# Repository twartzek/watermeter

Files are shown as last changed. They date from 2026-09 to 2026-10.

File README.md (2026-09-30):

# WatermeterAI NextGen 💧

Turns a photo of an ordinary analog water meter into a continuous digital reading — no smart meter, no retrofit, just a Raspberry Pi, a camera, and a YOLO model reading the dials like a person would.







<p align="center">
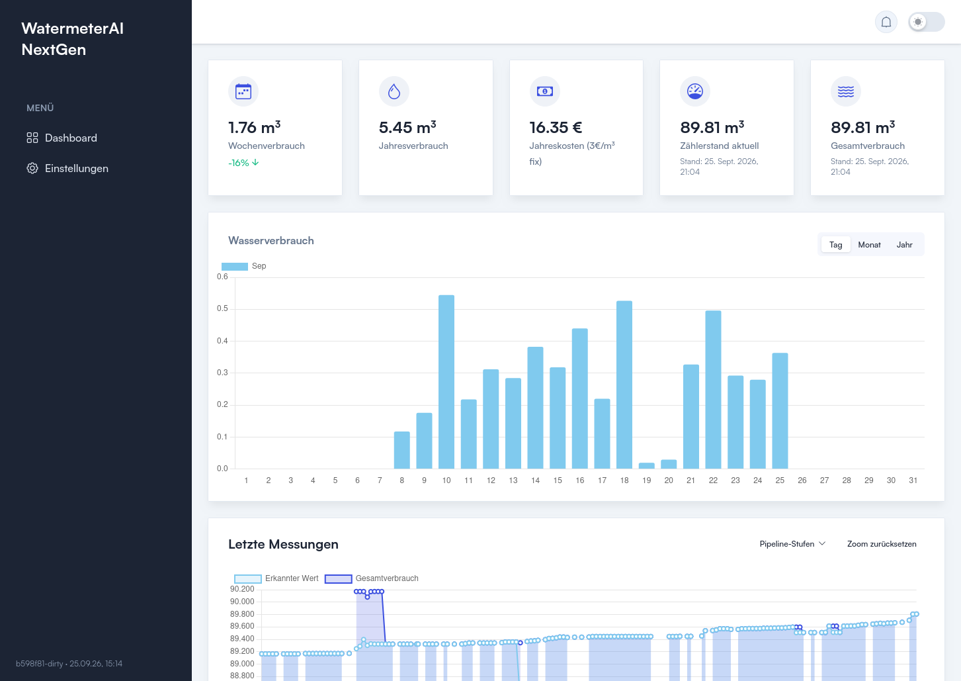
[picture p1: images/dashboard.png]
WatermeterAI NextGen dashboard
  
</p>

Every 15 minutes, a camera photographs the meter's dial face and a pair of YOLO models reads the digit wheels and sweep needles into one cumulative value, which is filtered for outliers, stored, and pushed to a dashboard and MQTT. A nightly job watches the trend for the signature of a leak and emails a warning before it becomes a water bill.

## Contents

- [WatermeterAI NextGen 💧](#watermeterai-nextgen-)
  - [Contents](#contents)
  - [Installation](#installation)
  - [Local development](#local-development)
    - [Verifying a deploy](#verifying-a-deploy)
  - [Configuration reference](#configuration-reference)
  - [How it works](#how-it-works)
  - [Model training](#model-training)
  - [Hardware](#hardware)
    - [What it costs](#what-it-costs)
  - [Leak detection](#leak-detection)
  - [Repository layout](#repository-layout)
  - [Known limitations](#known-limitations)
  - [Credits](#credits)
  - [License](#license)

## Installation

The intended target is a fresh Raspberry Pi OS install (Bullseye or newer, 64-bit recommended for `torch`/`ultralytics`).

```bash
git clone https://github.com/twartzek/watermeter
cd watermeter
sudo bash setupscript.sh
```

`setupscript.sh` is idempotent-ish but not fully — read it before running it twice. It will:

1. Increase swap to 2 GB (YOLO inference is memory-hungry on a Pi Zero 2)
2. Install system packages (`python3-picamera2`, `zbar-tools`, `npm`, `watchdog`)
3. Create a Python venv and install the pinned backend dependencies
4. Write `/home/admin/watermeter/.env` with the paths the backend expects
5. Register two `systemd` services and three cron jobs (measurement every 15 min, leak check nightly, photo cleanup nightly)
   - Readings are kept at full 15-minute resolution forever. At ~100 bytes per row that is only ~4 MB per year, and the leak detector's baseline window (`BASELINE_LOOKBACK_DAYS`, currently 30 days) can be extended if needed.
   - The photos are what fills the SD card, so the nightly cleanup keeps every photo for the last 30 days only. On older days it keeps just the photos of the first and last reading, and it also removes older orphaned photos from failed recognitions.
6. Configure a hardware watchdog that reboots the Pi if the reading log goes stale

Build the frontend once, so the systemd service has something to serve:

```bash
cd frontend
npm install
npm run build   # outputs to frontend/dist, served by `serve` on :80
```

On first boot with no WiFi configured, `backend/wifi.py` waits for a WiFi-credentials QR code (printed on a router, or from any "share WiFi" phone feature) to be shown to the camera — no keyboard or monitor needed.

## Local development

No Pi or camera needed to work on the dashboard/API — `requirements.txt` covers everything else:

```bash
cd backend
python3 -m venv .venv && source .venv/bin/activate
pip install -r requirements.txt

cp .env.example watermeter/.env   # see Configuration reference below
python seed_dev_data.py           # optional: populate SQLite with sample readings
python restapi.py                 # → http://localhost:8000/api/v1
```

```bash
cd frontend
npm install
npm run dev                       # → http://localhost:5173
```

Run the test suite with:

```bash
cd backend
pytest
```

`requirements-pi.txt` (`ultralytics`, `torch`, `opencv-python`, `pyzbar`, `Pillow`) is only needed for the actual image-reading pipeline, on hardware that can run YOLO inference.

### Verifying a deploy

Every frontend build stamps itself with its short git commit hash (`git rev-parse --short HEAD` in [`frontend/vite.config.js`](frontend/vite.config.js), plus `-dirty` for uncommitted changes), shown at the bottom of the dashboard sidebar — compare it against your local `git rev-parse --short HEAD` after `deploy.sh` to confirm the Pi picked up the latest build.

## Configuration reference

Install-specific config lives in two places, both deliberately excluded from version control:

| File | Holds | Set by |
|---|---|---|
| `watermeter/.env` | Filesystem paths — DB file, image folder, log folder, model weight paths | `setupscript.sh` on install |
| `data/settings.json` | MQTT broker credentials, SMTP credentials | Dashboard's Settings page, or manually on first run |

> **Network exposure:** The REST API has permissive CORS and no authentication — built for a trusted home LAN. Don't port-forward `:8000`/`:80` without a reverse proxy and auth in front.

## How it works

```mermaid
flowchart TB
    cam["📷 Pi Camera<br/><small>every 15 min</small>"]
    read["readTotalConsumption.py<br/><small>2× YOLO11<br/>digits + needles</small>"]
    presence["missing-box check<br/><small>discard incomplete reads</small>"]
    filt["outlierDetection.py<br/><small>digit · flow · delta<br/>filters</small>"]
    db[("SQLite<br/><small>readings + images</small>")]
    mqtt["MQTT broker"]
    api["restapi.py<br/><small>FastAPI :8000</small>"]
    dash["React dashboard<br/><small>:80</small>"]
    leak["leakageDetector.py<br/><small>Z-score + Isolation<br/>Forest · daily</small>"]
    warn["✉️ Email + MQTT<br/><small>notifications</small>"]
    wdog["watchdog<br/><small>reboots on hang</small>"]

    cam -->|photo| read
    read -->|raw m³| presence
    presence -->|passed| filt
    filt -->|store| db
    db -->|publish| mqtt
    db -->|read| api
    api -->|JSON| dash
    db -.->|30-day history| leak
    leak -.->|3× flagged| warn
    read -.->|watches for a hang| wdog

    style read fill:#b5672f,color:#fff,stroke:#8a4d22
    style db fill:#b5672f,color:#fff,stroke:#8a4d22
    style api fill:#b5672f,color:#fff,stroke:#8a4d22
    style leak fill:#b5672f,color:#fff,stroke:#8a4d22
```

*Solid arrows run every 15 minutes; dashed arrows (leak detector) run nightly and only speak up after three consecutive flagged days. A watchdog reboots the Pi if a run ever hangs.*

**Reading pipeline.** Two YOLO11 models read the digit wheels and sweep needles into a cumulative m³ value; a red-pixel check locates the decimal point, since the fractional wheels are printed red.

<p align="center">
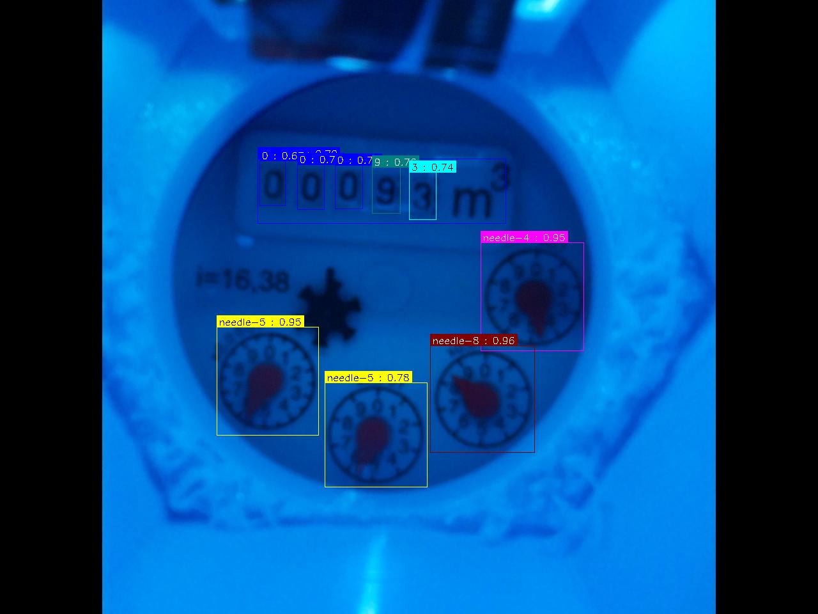
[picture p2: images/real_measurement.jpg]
YOLO detections on a real meter photo: five digit boxes and four needle boxes with confidence scores
  
</p>

*A real frame from the housing camera: the digit model finds each wheel (`0 0 0 9 3`), the needle model reads the four red dials — together 93.4855 m³.*

**Outlier filtering.** A missing-box check discards incomplete frames outright. Accepted values then pass missing-digit, max-flow (rate + absolute cap), and negative-delta filters — a single bad reading falls back to the local median, but a sustained run of consistent higher readings is accepted as real (e.g. a pipe burst) and triggers a notification instead of being clamped forever.

**Storage and delivery.** Readings, images, and every intermediate pipeline value land in SQLite, publish to MQTT, and are served by FastAPI to the React dashboard. Developer mode exposes each pipeline stage as its own chart line.

## Model training

The two YOLO11 models in `backend/models/` were trained on **3,516 images** from several sources — web photos, synthetically generated dials, and composited images — to cover a wide range of meter appearances, lighting, and angles, so the model doesn't overfit to one setup.

| Model | Task | Precision | Recall | mAP50 | mAP50-95 | Epochs |
|---|---|---|---|---|---|---|
| `totalandneedles/best.pt` | Needle position + counter-area detection | 0.894 | 0.882 | 0.906 | 0.852 | 100 |
| `digits/best.pt` | Digit-wheel detection (0–9 + red/transition class) | 0.964 | 0.908 | 0.948 | 0.826 | 100 |

The higher digit-detection precision (0.96 vs. 0.89) reflects that digit wheels are a more visually consistent target than needle position, which varies more geometrically across meter models. The two models' errors are largely independent, which is part of why the outlier filters downstream catch what either model gets wrong on its own.

If retraining for a different meter design, keep the same split (needles/counter-area vs. digit wheels). Training scripts and the raw dataset aren't included here, but the label format follows standard Ultralytics YOLO conventions — any compatible pipeline (e.g. [Roboflow](https://roboflow.com) or local [Ultralytics](https://docs.ultralytics.com/)) will work.

## Hardware

`Raspberry Pi Zero 2 W (or better)` · `Pi Camera Module` · `Custom LED light (KiCad)` · `3D-printed mount (FreeCAD)`

<p align="center">
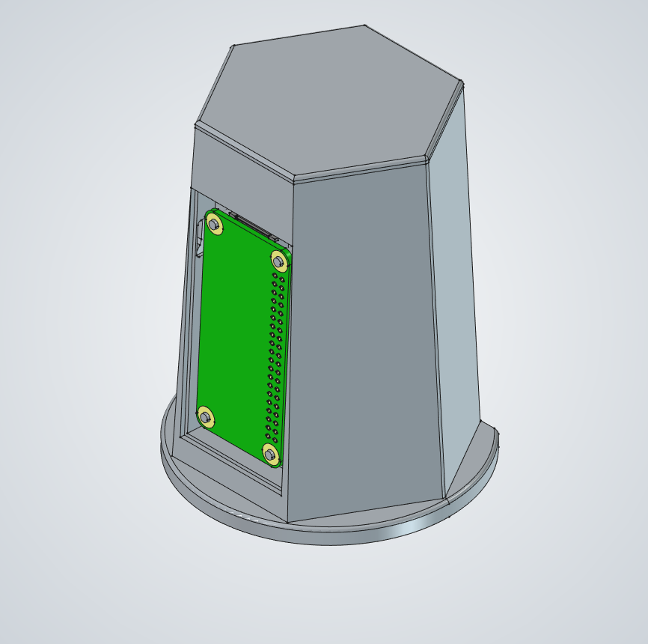
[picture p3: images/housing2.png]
CAD model of the camera and LED housing
  
  &nbsp;&nbsp;
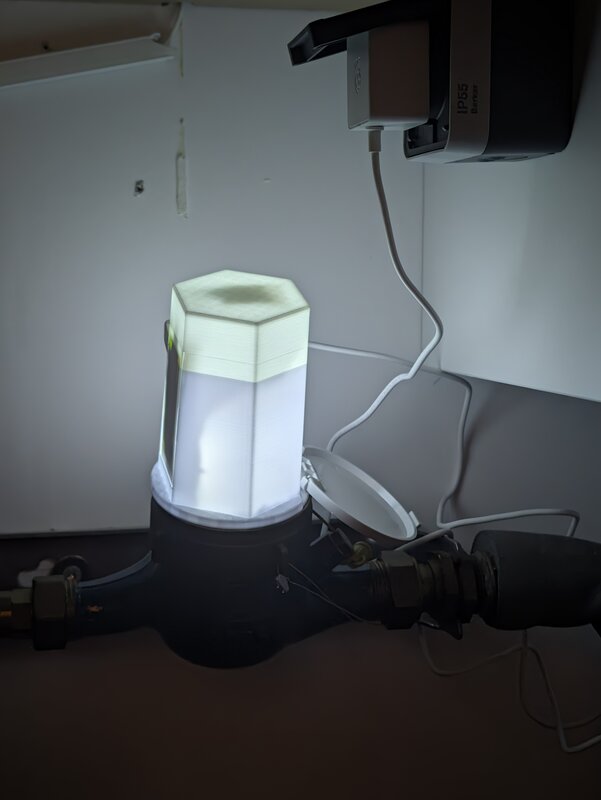
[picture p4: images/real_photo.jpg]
Printed housing installed on a real water meter, LED lit
  
</p>
<p align="center"><sub>Left: FreeCAD model · Right: installed on the meter</sub></p>

The camera and a custom LED light source (schematic/PCB in [`hardware/led/`](hardware/led/)) sit inside a 3D-printed bracket ([`mechanics/`](mechanics/)) that clips over the meter's glass face — no plumbing work, no meter replacement. Camera and LED are offset from each other at an angle chosen so the glass's specular reflection is thrown away from the camera instead of back into it, which is the single biggest source of misreads.

### What it costs

The compute and imaging side is deliberately cheap — accuracy comes from the YOLO models and lighting, not the hardware:

| Part | Price |
| --- | --- |
| Raspberry Pi Zero 2 W | ~€20 / $15 |
| Camera module (e.g. RPIZ-CAM-GS) | ~€15 |
| **Total (board + camera)** | **~€35 / ~$40** |

Add a power supply, SD card, the LED board, and a printed bracket (see [`hardware/`](hardware/) and [`mechanics/`](mechanics/)) and you're realistically still under €50 all in. Prices fluctuate by retailer; check current listings.

> **Reproducing the hardware:** PCB and enclosure files are provided as-is. You'll need KiCad for `hardware/led/led.kicad_pcb` and FreeCAD for the `mechanics/*.FCStd` models — expect to adapt the bracket geometry, since glass diameter/depth vary by meter manufacturer.

## Leak detection

`leakageDetector.py` runs nightly and combines three independent signals, since a slow leak, a stuck-open valve, and a burst pipe each look different in the reading history:

| Check | Catches | How |
|---|---|---|
| Rest-period check | Flow that never fully stops in 24h | Looks for any window where consecutive readings stay within an adaptive noise threshold |
| Z-score model | A quiet-hour slot (e.g. 3am) running unusually high | Compares each time-of-day slot's rolling 30-min sum against its own 30-day distribution |
| Isolation Forest | Unusual combinations — steady flow at an odd hour, an odd-sized single spike | Unsupervised model trained on flow, streak length, and time-of-day features |

A single flagged night doesn't trigger a warning — three consecutive nights do, trading a day or two of latency for not emailing you every time the dishwasher runs at an odd hour.

## Repository layout

| Path | What lives there |
|---|---|
| `backend/` | FastAPI server, YOLO reading pipeline, leak detector, SQLite models |
| `backend/models/` | Trained YOLO11 weights (digits, needles+counter-area) |
| `backend/tests/` | Pytest suite — pure-function tests + a DB-backed integration test |
| `frontend/` | React + Vite dashboard (readings, charts, settings, notifications) |
| `hardware/led/` | KiCad schematic + PCB for the LED illumination board |
| `mechanics/` | FreeCAD models for the camera/light 3D-printed mounting bracket |
| `setupscript.sh` | Provisions a fresh Pi: swap, services, cron, watchdog, `.env` |

## Known limitations

- Reading accuracy depends on consistent lighting and a clean meter face — condensation, dirt, or an off-angle mount degrades YOLO's confidence.
- The bundled models were trained on one meter's dial design; a differently styled meter will likely need retraining.
- No authentication on the API or dashboard — see the CORS callout above.
- The Pi Zero 2 W is workable but slow for inference; a Pi 4/5 gives noticeably faster latency.

## Credits

Inspired by [jomjol/AI-on-the-edge-device](https://github.com/jomjol/AI-on-the-edge-device), which pioneered reading analog utility meters with on-device ML on an ESP32. WatermeterAI NextGen takes a different path: a Raspberry Pi's extra headroom, YOLO object detection instead of digit-segment classification, and a camera/LED geometry that avoids glare — aiming for accurate readings straight out of the box, with no per-install calibration.

## License

Backend and hardware design files: MIT — see [`LICENSE`](LICENSE).

The frontend is built on [Reactwind](https://github.com/imarpanpatra/Reactwind) by Arpan Patra, also MIT-licensed — see [`frontend/LICENSE.md`](frontend/LICENSE.md) for its original attribution.

---

Built around one household's water meter. Pull requests that make it work with more meter styles, or that harden the network story, are welcome.

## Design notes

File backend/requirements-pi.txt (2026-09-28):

# Extra dependencies needed ONLY on the Raspberry Pi, for the actual
# camera/YOLO meter-reading pipeline (readTotalConsumption.py, results.py,
# wifi.py -- QR code / WiFi setup). Not needed for local frontend/API dev,
# see requirements.txt for that.
#
# Left unpinned on purpose: torch/ultralytics/opencv builds for ARM are
# often installed from Pi-specific wheels/indices rather than plain PyPI,
# so pin these yourself to whatever versions you've verified work on your
# Pi's OS/Python combination.
#
# Install with: pip install -r requirements.txt -r requirements-pi.txt
ultralytics
torch
opencv-python
pyzbar
Pillow
scikit-learn

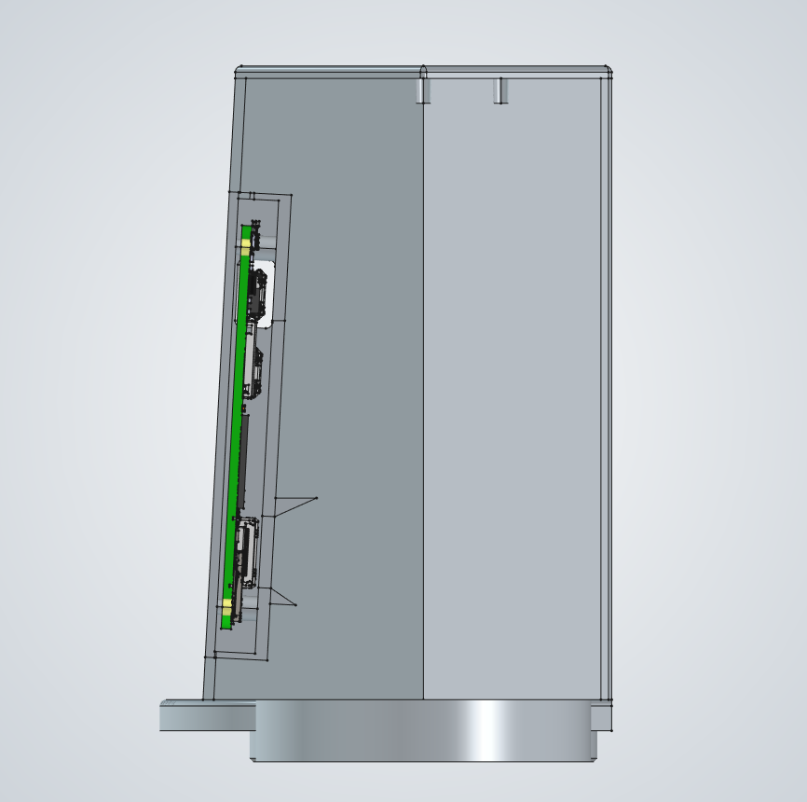
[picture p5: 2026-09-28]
images/housing3.png

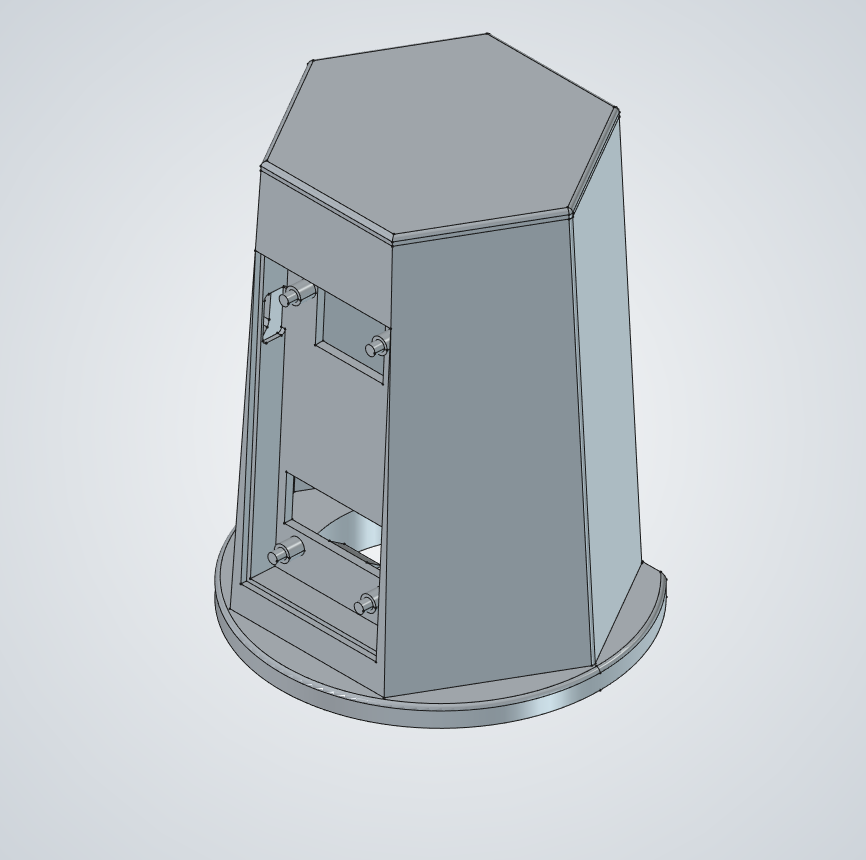
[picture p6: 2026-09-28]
images/housing.png

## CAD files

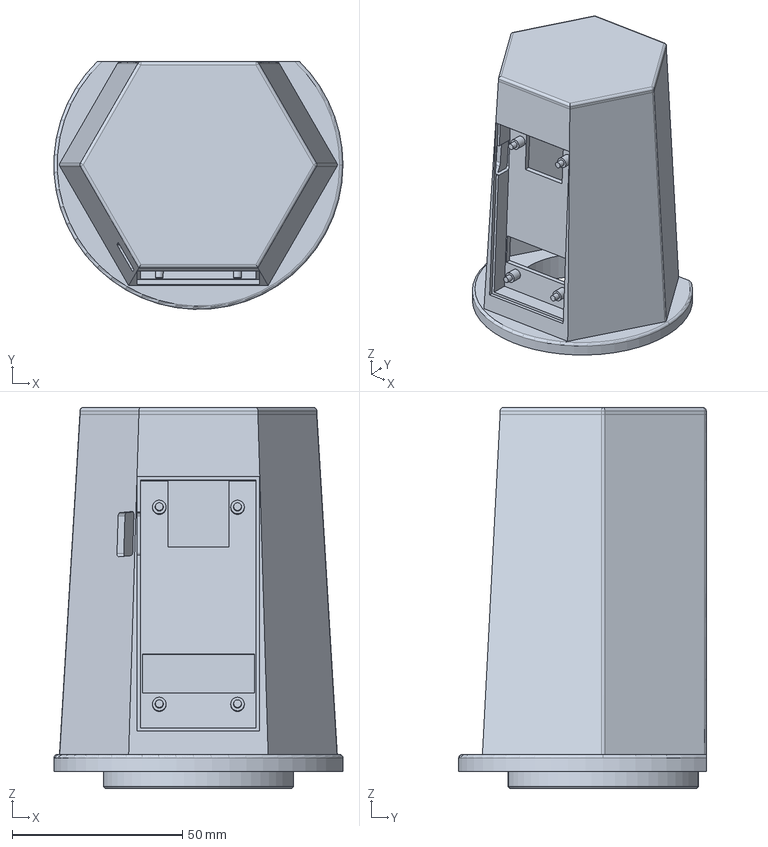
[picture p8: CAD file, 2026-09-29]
mechanics/watermeter.FCStd
84.9 x 72.8 x 112.0 mm

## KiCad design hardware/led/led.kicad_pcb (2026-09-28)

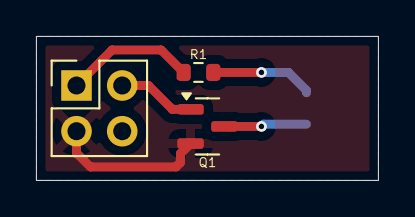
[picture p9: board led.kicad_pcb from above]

Board: 2 copper layers, 19.0 x 8.0 mm, 4 parts (1 on the bottom side), 5 nets.

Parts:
D1: LED; LED_0603_1608Metric_Pad1.05x0.95mm_HandSolder
J1: Conn_02x02_Odd_Even; PinHeader_2x02_P2.54mm_Vertical
Q1: PDTC123JT; SOT-23
R1: 100; R_0603_1608Metric

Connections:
+5V: J1.1, R1.1
GND: J1.3, Q1.2 (E)
unnamed: D1.2 (A), R1.2
unnamed: D1.1 (K), Q1.3 (C)
unnamed: J1.2, Q1.1 (B)

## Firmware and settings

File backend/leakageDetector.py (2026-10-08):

import pandas as pd
from datetime import datetime, timedelta
from db import get_last_readings, get_readings_since, addNotification, getKeyValueStoreValue, setKeyValueStoreValue
from emailhandler import sendEmail
from mqtt import mqtt_publish
from mylog import Logger

logger = Logger("leakageDetector")

# How many days of history to pull for the adaptive baseline models
# (Z-score, Isolation Forest). Readings are kept at full resolution forever
# (only old photos are thinned out, see db.py:thin_out_old_images), so this
# can be raised -- at the cost of an older, possibly less representative
# baseline (seasonal usage) and longer Isolation Forest training on the Pi.
BASELINE_LOOKBACK_DAYS = 30

# Readings are taken every 15 minutes -> 96 slots per day. Must match the
# cron interval set in restapi.py (job_readmeasurement.minute.every(...)) --
# if that changes, this needs to change with it, or the per-slot baseline
# statistics below silently compare readings against the wrong time-of-day
# bucket.
SLOT_MINUTES = 15
SLOTS_PER_DAY = 24 * 60 // SLOT_MINUTES

# Lower bound for the adaptive threshold, in m^3 (same unit as the
# 'filtered' reading, see readTotalConsumption.py:gettotalconsumption).
# Keeps the detector from becoming overly sensitive when the recent window
# happens to be unusually clean (e.g. right after startup), since MAD would
# otherwise estimate near-zero noise. Set to 0.002 m^3 (2 liters) as a
# conservative estimate of the YOLO reading's jitter -- NOT 1.0, which
# would mean 1000 liters of slack per 24h window and mask real leaks.
MIN_NOISE_THRESHOLD = 0.002

# A gap between two consecutive readings wider than this is treated as a
# measurement outage (camera down, Pi offline, ...) rather than normal
# sampling jitter around the SLOT_MINUTES interval. The reading right after
# such an outage carries no usable per-interval flow (see
# compute_flow_features); the history BEFORE the outage stays part of the
# baseline.
GAP_THRESHOLD_HOURS = 6.0

# How many readings before and after an increase compute_robust_flow looks
# at to decide whether that increase is real consumption or just one half
# of a misread. The 'filtered' reading is not reliably monotonic: a digit
# sitting right between two values gets read as either one from photo to
# photo (observed in production: the 0.1 m^3 digit flipping back and forth
# at night, e.g. 93.8936 -> 93.9936 -> 93.8936, i.e. 100 "liters" appearing
# and vanishing with no real flow at all). Bounded rather than unlimited on
# purpose: every misread hides real flow of up to its own size inside this
# window, so the window caps how long the models can be blinded by one.
FLOW_CONFIRMATION_WINDOW = 2

# Hours of the day (local time, [start, end)) in which a household is
# normally asleep. Flagged readings in these hours are judged by a rule of
# their own in select_leak_signal_readings (QUIET_HOURS_MIN_ANOMALIES)
# instead of the daytime one (DAYTIME_MIN_CONSECUTIVE_ANOMALIES): a leak
# doesn't stop at bedtime, ordinary consumption mostly does, so the night
# is where a leak stands out with the least water.
QUIET_HOURS_START = 0
QUIET_HOURS_END = 5

# Outside the quiet hours a flagged reading only counts as a leak signal if
# it is part of a run of at least this many flagged readings in a row (~1h
# at SLOT_MINUTES sampling), each with flow of its own. Both models flag
# whatever is unusual compared to the baseline, and during the day a single
# flag is mostly just an ordinary but large draw (shower, washing machine)
# -- Isolation Forest in particular flags a fixed share of readings no
# matter what (see contamination in compute_isolation_forest_anomalies).
# What sets a leak apart from that is that it doesn't stop. Keeps the
# models' ability to catch a leak that only runs during the day (which the
# dual check and, below its rate threshold, detectSustainedHighFlow() both
# miss) without alarming on every large single draw.
DAYTIME_MIN_CONSECUTIVE_ANOMALIES = 4

# During the quiet hours, at least this many flagged readings (each with
# flow of its own, anywhere within those hours -- not necessarily in a row)
# are needed before they count as a leak signal. A single one is what real
# night-time use looks like (observed in production: a 116 L shower at
# 00:05, 50 L at 04:19 -- each one draw, each flagged by both models).
QUIET_HOURS_MIN_ANOMALIES = 3

# compute_zscore_anomalies: a reading only counts as anomalous if it also
# exceeds this quantile of what the same time of day has seen in the
# baseline, pooled over all slots within ZSCORE_USUAL_NEIGHBOURHOOD_MINUTES
# of the reading's own slot. Needed because the per-slot z-score alone
# knows next to nothing about how much a slot really varies: most slots are
# at zero on most days, so the MAD-based std sits on its min_std floor
# nearly everywhere and the z-score degenerates into "more than ~8 liters
# in 30 minutes" -- which is any ordinary draw that happens to land in a
# slot it didn't land in before (observed in production: with 3-4 weeks of
# baseline it flagged 5 of 15 leak-free days this way). One slot's 20-30
# observations can't tell "never happens around this time" from "happens,
# just not in this exact quarter of an hour"; a couple of hundred
# observations from the surrounding two hours can.
ZSCORE_USUAL_QUANTILE = 0.95
ZSCORE_USUAL_NEIGHBOURHOOD_MINUTES = 60

# The Z-score and Isolation Forest models are skipped entirely unless the
# baseline (see get_baseline_readings_as_timeseries) has readings on at
# least this many days (see count_baseline_days). Two
# full weeks, so every weekday's routine (laundry day, weekend) is in the
# baseline at least twice before "unusual compared to the baseline" is
# taken as a leak signal. Until then detection rests on the dual check and
# detectSustainedHighFlow(), neither of which needs any history.
MIN_BASELINE_DAYS = 14

# detectSustainedHighFlow(): a flow of at least SUSTAINED_FLOW_MIN_RATE
# (m^3/h) held over SUSTAINED_FLOW_MIN_READINGS consecutive readings (~1h
# at SLOT_MINUTES sampling) is reported right away instead of waiting for
# the daily detectLeakage() run and its 3-day debounce. Fills the gap below
# outlierDetection.maxFlowDetector's own immediate alarm, which only
# triggers above MAXFLOW (60 L/min) -- a burst of a few hundred L/h never
# gets there. Showers and the like reach far higher rates than 150 L/h,
# but only for 1-3 readings. Deliberate long draws (watering the garden,
# filling a pool) look exactly like a burst to the meter and DO trigger
# this -- in 26 days of production history that happened once (~530 L/h
# over 3 hours); accepted, since one email for 1.7 m^3 in an afternoon is
# the point of this check.
SUSTAINED_FLOW_MIN_RATE = 0.15
SUSTAINED_FLOW_MIN_READINGS = 4

# Minimum time between two detectSustainedHighFlow() warnings, so a flow
# that keeps running doesn't send a new email with every single reading.
SUSTAINED_FLOW_WARNING_COOLDOWN_HOURS = 24

# Minimum number of historical observations a time-of-day slot needs before
# compute_zscore_anomalies trusts its mean/std enough to flag anything in
# it. Any spread estimate (std or MAD) computed from just 2-5 points is
# mostly sampling noise, not a real measurement of "how much this slot
# normally varies" -- a fresh install has EVERY slot starting from 0 observations and climbing by ~1 per
# day, so this directly controls how many days a slot needs to "warm up"
# before the model will flag it (BASELINE_LOOKBACK_DAYS=30 is the ceiling
# on history it will ever consider, not a guarantee that a slot has that
# many observations yet). 10 was chosen over the previous 3 after a
# production incident where 3-5 observations per slot (site was ~1 week
# old) produced triple-digit z-scores on ordinary jitter.
#
# DELIBERATE TRADE-OFF, not just a side effect: during the ~10-day warm-up
# this makes the Z-score model blind to real leaks too, not only false
# positives (verified: a realistic 12 L/h leak injected into the real,
# ~7-day-old production baseline was NOT flagged by this model with any
# min_std, because every slot's count fell short of this threshold before
# min_std ever entered the calculation). That's accepted rather than worked
# around (e.g. by relaxing the threshold or special-casing all-zero slot
# histories) because find_stable_periods_dual_check and Isolation Forest's
# own min_training_rows are this detector's other two signals, don't
# depend on any single slot's history, and both DID catch that same
# injected leak -- detectLeakage()'s overall sensitivity during warm-up
# rests on them, not on this one. Once a slot has genuinely earned this
# many observations, MAD-based std (see _mad_std) does correctly separate
# ordinary jitter from a real leak's excess volume.
ZSCORE_MIN_SLOT_OBSERVATIONS = 10


def estimate_noise_threshold(time_series: pd.Series, k: float = 6.0, min_threshold: float = MIN_NOISE_THRESHOLD) -> float:
    """
    Estimate a noise threshold for consecutive-step comparisons from the
    time series itself, so isolated detection-algorithm jitter (e.g. YOLO
    misreads causing +/- a few units around a true-zero flow) doesn't get
    mistaken for real consumption.

    Uses the Median Absolute Deviation (MAD) of consecutive differences,
    scaled to be comparable to a standard deviation, times a safety factor k.
    MAD is used instead of std() because it isn't dragged around by the
    (rare, but expected) large genuine-consumption steps mixed into the
    same window.

    Since the cumulative meter reading never decreases (upstream outlier
    filtering already drops negative deltas) and most SLOT_MINUTES intervals
    in a real household see zero consumption, the raw diff series is
    dominated by exact zeros. Including those would pull the MAD down to
    ~0 regardless of how noisy the actual (non-zero) readings are, so the
    noise scale is estimated from the positive diffs only -- these are the
    ones that actually carry the detection algorithm's read-to-read jitter.

    Parameters:
    time_series (pd.Series): the readings to estimate noise from.
    k (float): safety multiplier applied to the estimated noise scale.
    min_threshold (float): floor for the returned threshold.

    Returns:
    float: threshold to use for `find_stable_periods_dual_check`.
    """
    diffs = time_series.diff().dropna()
    positive_diffs = diffs[diffs > 0]
    if positive_diffs.empty:
        return min_threshold

    median_diff = positive_diffs.median()
    mad = (positive_diffs - median_diff).abs().median()
    # Consistency constant to make MAD comparable to a standard deviation
    # under normally distributed noise.
    noise_std_estimate = mad * 1.4826

    threshold = k * noise_std_estimate
    return max(threshold, min_threshold)

def get_last_readings_as_timeseries():
    """
    Retrieve the last SLOTS_PER_DAY readings (24h at SLOT_MINUTES sampling)
    from the database and transform them into a Pandas time series.

    A measurement gap in here needs no special handling: it just becomes a
    large step in find_stable_periods_dual_check's diff, which correctly
    ends any stable-period candidate at that point without ever being
    mistaken for one (a stable period requires the diff to stay *below*
    the noise threshold).

    Parameters:
    db_connection (object): Database connection object
    table_name (str): Name of the table to retrieve readings from

    Returns:
    pd.Series: Pandas time series object containing the last SLOTS_PER_DAY
        readings.
    """
    # Retrieve the last 24h worth of readings from the database.
    readings = get_last_readings(SLOTS_PER_DAY)
    data = []
    readings = sorted(readings, key=lambda x: x.time)
    for r in readings:
        data.append((r.time, r.filtered))
    
    # Create a Pandas DataFrame from the readings. dtype=float is needed
    # for the empty-readings case (e.g. right after a fresh install): an
    # empty DataFrame column defaults to dtype=object, which fails the
    # numeric-dtype check in find_stable_periods_dual_check.
    df = pd.DataFrame(data, columns=['timestamp', 'value']).astype({'value': 'float64'})

    # Convert the 'timestamp' column to datetime format
    df['timestamp'] = pd.to_datetime(df['timestamp'])

    # Set the 'timestamp' column as the index of the DataFrame
    df.set_index('timestamp', inplace=True)

    # Convert the DataFrame to a Pandas time series
    ts = df['value']

    return ts


def get_baseline_readings_as_timeseries(days: int = BASELINE_LOOKBACK_DAYS) -> pd.Series:
    """
    Retrieve the last `days` days of readings from the database as a Pandas
    time series, for use as the training/baseline window of the adaptive
    models below. Unlike get_last_readings_as_timeseries (fixed count, used
    by the original dual-check detector), this is time-bounded so the
    baseline always covers full days regardless of how many readings were
    actually taken (e.g. gaps from camera failures).

    Measurement outages inside the window are deliberately kept as they
    are instead of cutting the baseline off at the last one: the reading
    right after an outage is excluded as a flow value anyway (see
    compute_flow_features), and what the household did before a few hours
    without photos is no less "normal" than what it did after. Cutting
    there used to throw away the whole history for outages barely over
    GAP_THRESHOLD_HOURS (observed in production: twice within a week, 6.5h
    and 7h), leaving the models without a usable baseline most of the
    time. History that really is stale ages out via `days` by itself.
    Whether what's left is enough to judge from is decided by the caller
    (see count_baseline_days).

    Returns:
    pd.Series: cumulative meter readings ('filtered'), indexed by timestamp.
    """
    readings = get_readings_since(days)
    data = [(r.time, r.filtered) for r in readings if r.filtered is not None]
    # See get_last_readings_as_timeseries for why dtype=float64 is forced
    # here (empty-readings case would otherwise yield dtype=object).
    df = pd.DataFrame(data, columns=['timestamp', 'value']).astype({'value': 'float64'})
    df['timestamp'] = pd.to_datetime(df['timestamp'])
    df.set_index('timestamp', inplace=True)
    return df['value']


def compute_robust_flow(time_series: pd.Series, window: int = FLOW_CONFIRMATION_WINDOW) -> pd.Series:
    """
    Per-interval flow from the cumulative reading, ignoring increases that
    are only the visible half of a misread.

    A plain diff().clip(lower=0) is NOT safe here: the 'filtered' reading is
    not reliably monotonic (see FLOW_CONFIRMATION_WINDOW), and clipping
    throws away the downward half of a misread while keeping the upward
    half as if it were real consumption. Which of the two readings was the
    wrong one can't be told from the pair alone -- but it doesn't have to
    be, since the meter itself can't run backwards. An increase is only
    real consumption if it holds up against BOTH sides:

    - it rises above everything read in the `window` readings before it
      (otherwise it's just the rebound after a too-low misread), and
    - nothing in the `window` readings after it falls back below it
      (otherwise it's a too-high misread that gets taken back).

    Implemented as the smaller of the step in the trailing rolling maximum
    and the step in the leading rolling minimum; on clean, monotonic data
    both envelopes equal the series itself and this reduces to a plain
    diff().

    The most recent `window` readings have less (or no) lookahead to be
    confirmed against, so a too-high misread right at the end of the
    series still counts as flow until later readings exist.

    Parameters:
    time_series (pd.Series): cumulative readings indexed by timestamp, ascending.
    window (int): how many neighbouring readings to each side an increase
        is checked against.

    Returns:
    pd.Series: flow per reading (>= 0), NaN for the first reading.
    """
    upper = time_series.rolling(window + 1, min_periods=1).max()
    lower = time_series[::-1].rolling(window + 1, min_periods=1).min()[::-1]
    # Measured against the neighbouring readings directly, not as the
    # envelopes' own diff(): those would also jump when an old misread
    # merely drops out of the rolling window.
    rise_above_past = time_series - upper.shift(1)
    held_by_future = lower - time_series.shift(1)
    flow = pd.concat([rise_above_past, held_by_future], axis=1).min(axis=1, skipna=False)
    return flow.clip(lower=0)


def compute_flow_features(time_series: pd.Series) -> pd.DataFrame:
    """
    Turn the raw cumulative meter reading into per-interval flow features
    used by both the Z-score and the Isolation Forest model.

    Columns:
    flow: consumption since the previous reading (>= 0; the meter is
        monotonic and negative deltas are already filtered upstream).
    active_flow_streak: number of consecutive readings (including this one)
        with flow > 0 -- mirrors 'dauer_aktiver_fluss' from the concept.
    rolling_sum_30m: sum of flow over the trailing 30 minutes of WALL-CLOCK
        time (a time-based rolling window, not a fixed count of readings)
        -- mirrors 'rollende_summe_30m'.
    hour_of_day, minute_of_day: time-of-day features. minute_of_day is
        rounded DOWN to the nearest SLOT_MINUTES bucket, not the exact
        minute -- see the minute_of_day note further below for why.

    A reading-to-reading gap wider than GAP_THRESHOLD_HOURS (measurement
    outage, e.g. camera down) has its flow value dropped rather than
    diffed: otherwise the entire consumption accumulated during the
    outage -- hours to months worth -- would show up as a single flow
    reading, an outlier disproportionate to actual per-interval flow.

    rolling_sum_30m deliberately uses a time-based window ('30min'), not a
    row-count window (e.g. round(30/SLOT_MINUTES) readings): readings are
    NOT reliably equidistant at SLOT_MINUTES apart -- a failed detection
    (bad lighting, a discarded outlier, a watchdog reboot mid-inference,
    ...) simply produces no row for that slot rather than a placeholder, so
    a fixed-count window can silently span hours of wall-clock time after a
    gap while still calling itself "30 minutes". That inflates
    rolling_sum_30m for the readings immediately following a gap (several
    real intervals' worth of flow lands in what the model believes is one
    30-minute window) and, symmetrically, corrupts the SAME slot's
    baseline statistics in compute_zscore_anomalies/compute_isolation_forest_anomalies
    whenever a gap happened to fall in the history window -- either can
    produce a spurious leak flag with the readings themselves looking
    unremarkable (observed in production: three nights of Z-score/Isolation
    Forest flags with every underlying reading at/near zero flow, traced
    back to this). A time-based window only ever sums flow that actually
    occurred within the trailing 30 minutes, regardless of how many (or
    how few) rows happen to fall in it.
    """
    df = pd.DataFrame({'value': time_series})
    df['flow'] = compute_robust_flow(df['value'])

    gaps = df.index.to_series().diff()
    df.loc[gaps > pd.Timedelta(hours=GAP_THRESHOLD_HOURS), 'flow'] = float('nan')

    is_flowing = df['flow'] > 0
    # Length of the current run of flowing readings, reset to 0 whenever
    # flow stops (or at the very first reading, where diff() is NaN).
    groups = (~is_flowing).cumsum()
    df['active_flow_streak'] = is_flowing.groupby(groups).cumsum()

    # Time-based window -- see the rolling_sum_30m docstring note above for
    # why this must not be a fixed row count. NaN flow rows (outages) are
    # skipped by sum() like any other NaN and don't poison the window; they
    # get dropped from the returned frame by dropna(subset=['flow']) below
    # anyway, since they were never a real per-interval flow reading.
    df['rolling_sum_30m'] = df['flow'].rolling('30min', min_periods=1).sum()

    df['hour_of_day'] = df.index.hour
    # Rounded DOWN to the nearest SLOT_MINUTES bucket, NOT the exact minute.
    # A reading nominally "every SLOT_MINUTES" still lands at a different
    # exact second/minute each time (camera-trigger jitter, and the
    # detection pipeline itself takes a variable few minutes -- see
    # YOLO_PREDICT_TIMEOUT_SECONDS in readTotalConsumption.py) -- e.g. three
    # consecutive ~06:04 readings landed at :04:11, :04:29, :04:36 exact
    # minute-of-day values 364 each time by coincidence, but the fourth
    # landed at :04:42 and would have missed that "slot" under exact-minute
    # grouping. Grouping by exact minute-of-day in compute_zscore_anomalies
    # therefore scatters what should be one coherent "around 06:00" sample
    # across many near-singleton groups, each with std=0 (or clipped to the
    # min_std floor) purely because they only ever saw 1-2 points --
    # trivially breached by any next reading whose flow differs even
    # slightly, producing spurious triple-digit z-scores on essentially
    # flat, unremarkable data (observed in production). Bucketing first
    # pools every reading "around" the same SLOT_MINUTES-wide window into
    # one group, giving slot_stats a realistic sample size to estimate mean/
    # std from.
    df['minute_of_day'] = (
        (df.index.hour * 60 + df.index.minute) // SLOT_MINUTES
    ) * SLOT_MINUTES

    return df.dropna(subset=['flow'])
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

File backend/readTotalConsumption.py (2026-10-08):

from ultralytics import YOLO
import cv2
import numpy as np
from db import store_reading
from results import ResultsExtended, plot_bboxes
import platform
import datetime
import gc
import multiprocessing
import os
import tempfile
import time
from dotenv import dotenv_values
from mqtt import mqtt_publish
from gpio import Led
from mylog import Logger
from scipy.ndimage import rotate
from PIL import Image
from outlierDetection import (
    missingDigitDetector,
    maxFlowDetector,
    negativeDeltaDetector,
    meterReplacementDetector,
    missingNeedleOrDigitDetector,
)

config = dotenv_values("watermeter/.env")


logger = Logger("readTotalConsumption")

try:
    from picamera2 import Picamera2
except ImportError:
    pass

led = Led(2)

# Fixed exposure instead of auto exposure: the LED is the only light source
# in the meter pit, and auto exposure blew out the blue channel on large
# parts of the image (see exposureTest.py). With the black cardboard lining
# inside the housing (against reflections on the digit window) only ~1/4 of
# the light reaches the meter, so 160 ms at gain 1.0 is needed for a dial
# brightness of ~155 (blue channel) without clipping in the dial/digit
# window; 40 ms (the value before the lining) was visibly too dark.
# Re-run exposureTest.py after changing LED/housing/lining.
CAMERA_CONTROLS = {"AeEnable": False, "ExposureTime": 160000, "AnalogueGain": 1.0}

# On the Pi Zero 2 W (416 MB RAM) it turned out that a hanging YOLO
# inference (e.g. due to extreme swap thrashing) doesn't surface as an
# exception but blocks the process indefinitely. The external `timeout` in
# startMeasurement.sh (see there) only kicks in later and the watchdog file
# check only after 15 minutes, which feels like the whole Pi has frozen.
# This timeout aborts a single YOLO predict call much earlier and in a
# controlled way.
#
# Originally implemented with signal.alarm(SIGALRM) -- which proved
# ineffective in practice: CPython only delivers SIGALRM between bytecode
# instructions, and a hanging native PyTorch/OpenCV call (especially under
# swap thrashing, where the call waits on I/O in the kernel) never returns
# to such a checkpoint, so the alarm is never delivered. Logs from the Pi
# showed 0 YoloTimeoutError for >550 runs that never finished -- the
# watchdog reboot was the only way out in practice. A
# multiprocessing.Process, on the other hand, can be killed hard by the
# operating system via SIGKILL, regardless of whether the child process is
# stuck in native code.
#
# 300s turned out to be too tight on the Pi Zero 2 W: the one-time
# ultralytics import + model loading in the worker (see
# _PredictWorkerHandle) alone takes a measured ~85s+~30s=~115s there, WHICH
# COUNTS AGAINST THIS TIMEOUT FROM THE START OF THE RESPECTIVE predict()
# CALL (the import happens on the very first call within the first
# run_predict()) -- under system load/swap pressure the remaining budget was
# no longer reliably enough for the actual inference (observed live on the
# Pi: a single predict() call alone > 300s, without any other load). 550s
# leaves enough headroom for both predict() calls. The outer `timeout` in
# startMeasurement.sh MUST be adjusted consistently when changing this
# (clearly larger than 2x this value, since both predict() calls have to
# fit into that outer timeout one after the other), otherwise it would hit
# before this inner, controlled timeout.
YOLO_PREDICT_TIMEOUT_SECONDS = 550


class YoloTimeoutError(Exception):
    pass


# Importing ultralytics + loading a model take a measured ~85s and ~30s on
# the Pi Zero 2 W (see git history/PR discussion) -- so the expensive
# import must not be repeated for every predict() call, otherwise the
# YOLO_PREDICT_TIMEOUT_SECONDS timeout is used up before the actual
# inference (exactly the bug this long-lived worker fixes). The model
# itself is deliberately NOT cached across several modelpaths: keeping the
# needle and digit models in memory at the same time overwhelms the Pi Zero
# 2 W (416 MB RAM is tight) -- that was already the rule before the switch
# to multiprocessing (del model; gc.collect() after each predict()). The
# worker therefore holds at most one loaded model at a time: if the next
# request switches to a different modelpath, the previous model is freed
# first.
_worker_model = None
_worker_modelpath = None


def _predict_worker(request_queue, result_queue):
    """
    Runs in the long-lived child process (see _PredictWorkerHandle).
    Accepts (modelpath, imagePath, predict_kwargs) requests from
    request_queue until None arrives as a sentinel. Holds at most one model
    loaded at any time (see comment above).
    """
    global _worker_model, _worker_modelpath
    while True:
        request = request_queue.get()
        if request is None:
            return
        modelpath, imagePath, predict_kwargs = request
        try:
            if _worker_modelpath != modelpath:
                del _worker_model
                gc.collect()
                _worker_model = YOLO(modelpath, task="detect")
                _worker_modelpath = modelpath
            results = _worker_model.predict(imagePath, **predict_kwargs)
            result_queue.put(("ok", results[0]))
        except Exception as e:
            result_queue.put(("error", e))
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

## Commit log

2026-09-28 feat: all files first versions
    [led-B_Cu.gbr, led-B_Mask.gbr, led-B_Paste.gbr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]
2026-09-29 - fix: 3D design fixed cam mounting and some smaller issues. - fix: optimized exposure settings and deploy script
    [watermeter.FCStd]
2026-09-30 feat: keep all readings at full resolution, thin out only old photos
    - Nightly cleanup no longer deletes readings. Readings cost ~4 MB per
    year, the photos are what fills the SD card. thin_out_old_images()
    (replaces delete_old_readings()) keeps every photo for 30 days and
    only the first/last photo per day after that.
    - API returns imageUrl=null when a reading's photo has been removed;
    the readings table shows a placeholder instead of a broken image.
    - getConPerYear() uses two index lookups per year instead of scanning
    the whole table; getConPerMonth/Day filter by time range so the
    time index is used as well.
    - Leak detector: BASELINE_LOOKBACK_DAYS is no longer capped by the
    ret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
    [cleanupdatabase.py, db.py, leakageDetector.py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]
2026-10-02 feat: rolling 7-day stats, new theme color, 160 ms exposure
    Frontend
    - Dashboard card compares the last 7 days with the 7 days before instead
    of calendar weeks; the change rate is now relative to the previous
    window and hidden when there is no previous value
    - New primary color (#4A5A8A) for headings, logo and favicon
    - Chart colors (line, text, grid) follow light/dark mode via the new
    useChartColors hook
    - Leak/high-flow markers in the chart are limited to the loaded
    readings, so old warnings no longer stretch the time axis
    - Loader is a falling water drop instead of a spinner
    Backend
    - Fixed exposure raised from 40 ms to 160 ms: the black cardboard lining
    in the housing lets onl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
    [cleanupdatabase.py, db.py, leakageDetector.py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]
2026-10-08 fix: stop false leak alarms from misread digits, add sustained-flow alert
    The leak detector emailed a leakage warning although no water was
    flowing at night. Cause: the 'filtered' reading is not monotonic (a digit
    between two values is read as either one), and diff().clip(lower=0)
    dropped the downward half of each misread while keeping the upward half
    as ~100 L of phantom flow.
    - compute_robust_flow: an increase only counts as flow if it rises above
    the 2 readings before it and is not undercut by the 2 after it
    - Z-score and Isolation Forest flags only count as a leak signal as
    several readings with flow of their own: >= 3 between 00:00 and 05:00,
    or >= 4 in a row at any time of day
    -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
    [leakageDetector.py, readTotalConsumption.py]

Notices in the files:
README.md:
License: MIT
